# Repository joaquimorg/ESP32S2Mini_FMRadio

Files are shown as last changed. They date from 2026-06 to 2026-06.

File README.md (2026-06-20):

🌐 **Português** · [English](README.en.md)

# ESP32-S2 Mini — Rádio FM (SI4703)

Firmware de um rádio FM para **Lolin S2 Mini (ESP32-S2)** com um pequeno LCD
**ST7789 de 76×284 px** usado em orientação paisagem (**284×76**).

O projeto inclui uma interface gráfica completa (7 ecrãs) com navegação por
4 botões físicos e controlo de um **SI4703** (FM + RDS) por I²C. As memórias e a
última sintonia/volume são **guardadas em NVS** (sobrevivem a desligar).

> Existe um interruptor `#define USE_SI4703` no topo de [src/main.cpp](src/main.cpp):
> a `1` usa o rádio real, a `0` usa um modelo simulado em RAM (útil para testar a UI).

---

## Hardware

- **MCU:** Lolin S2 Mini (ESP32-S2FNR2, 4 MB Flash, 2 MB PSRAM)
- **Display:** TFT ST7789, painel de **76×284 px** (offset dentro da RAM 240×320 do controlador)
- **Rádio:** SI4703 (FM + RDS), via I²C
- **Entrada:** 4 botões físicos (por baixo do display)
- **Áudio:** amplificador PAM8403 (2×3 W) + altifalante 8 Ω / 3 W

### Componentes

| Componente | Imagem | Descrição |
|---|:---:|---|
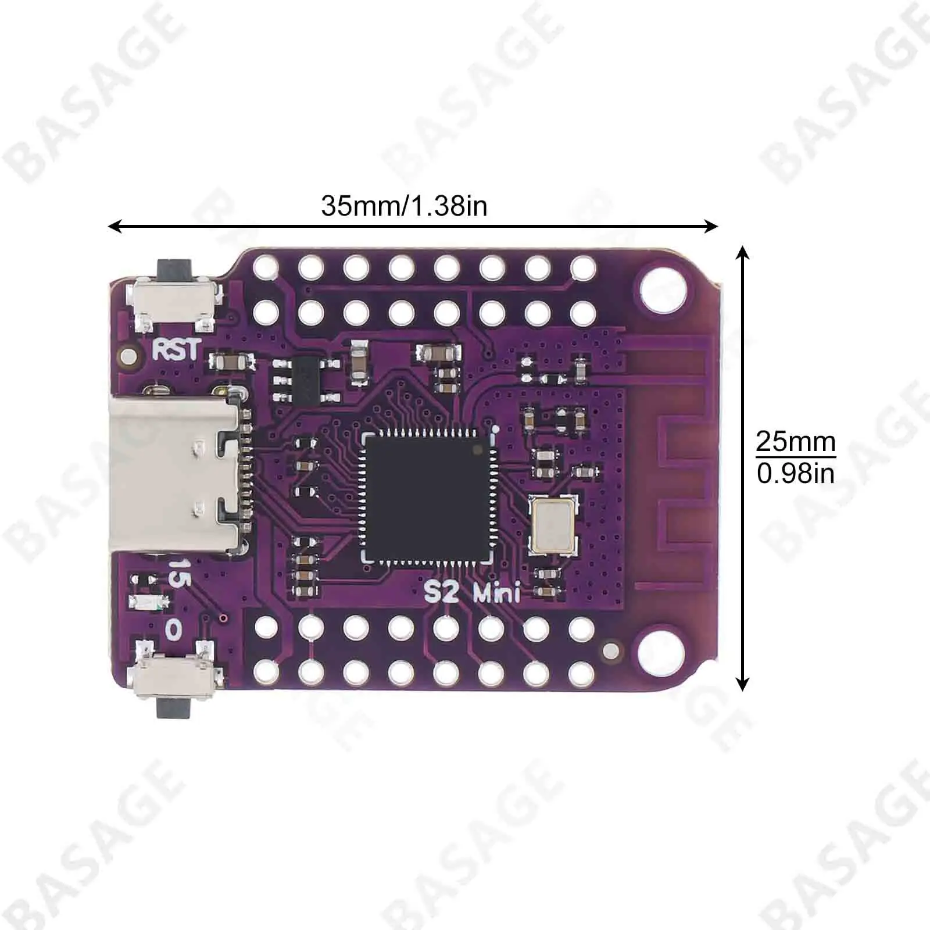
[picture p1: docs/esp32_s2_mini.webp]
| **Lolin S2 Mini** |  | MCU ESP32-S2 (35×25 mm), 4 MB Flash + 2 MB PSRAM, USB-C nativo. |
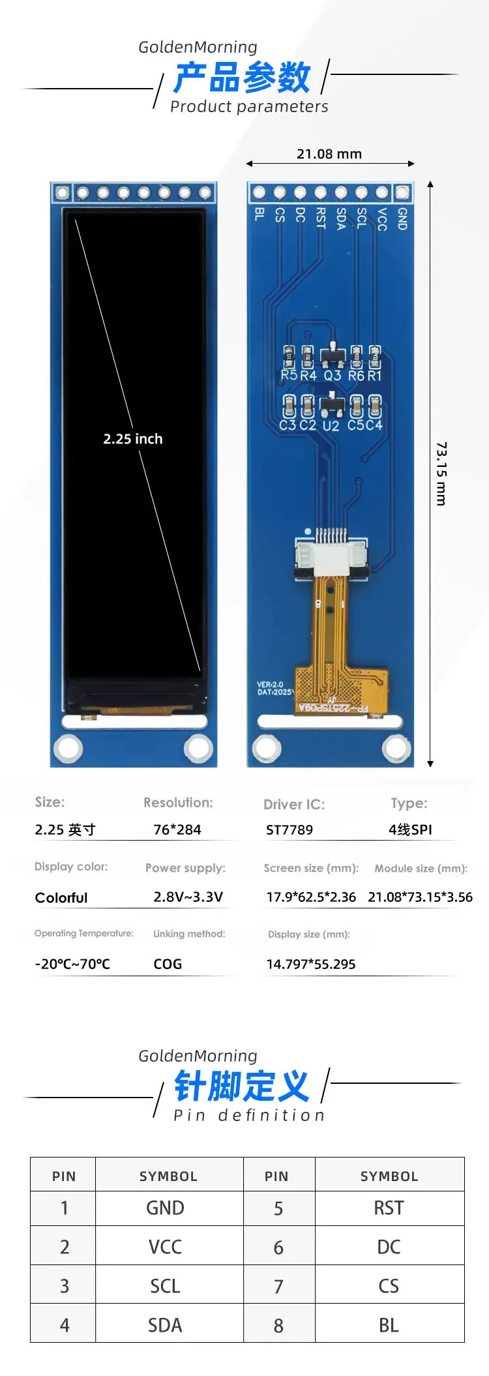
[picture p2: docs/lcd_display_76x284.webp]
| **Display ST7789** |  | TFT 2.25" a cores, 76×284 px, interface SPI de 4 fios, alimentação 2.8–3.3 V. |
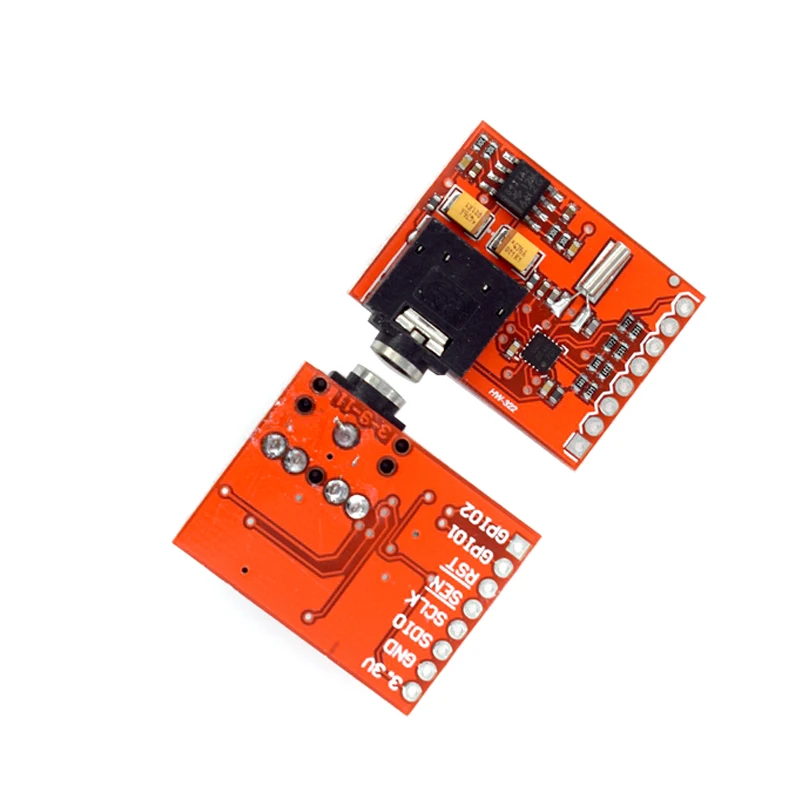
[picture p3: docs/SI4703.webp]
| **SI4703** |  | Recetor FM com RDS por I²C; jack de 3.5 mm que serve também de antena. |
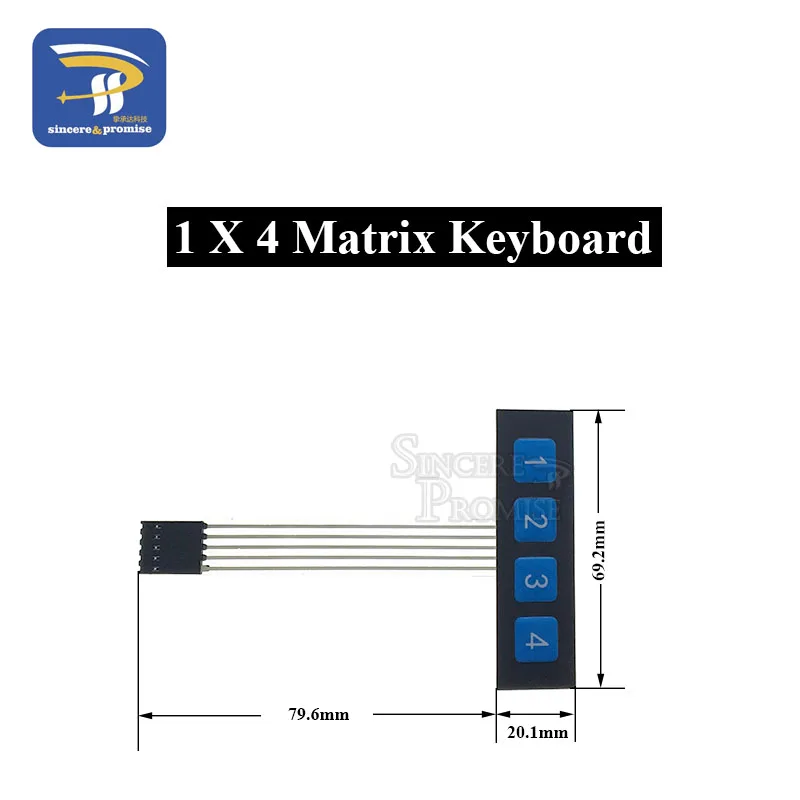
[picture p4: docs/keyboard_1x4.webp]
| **Teclado 1×4** |  | Membrana com 4 botões (BT1–BT4) usada para a navegação. |
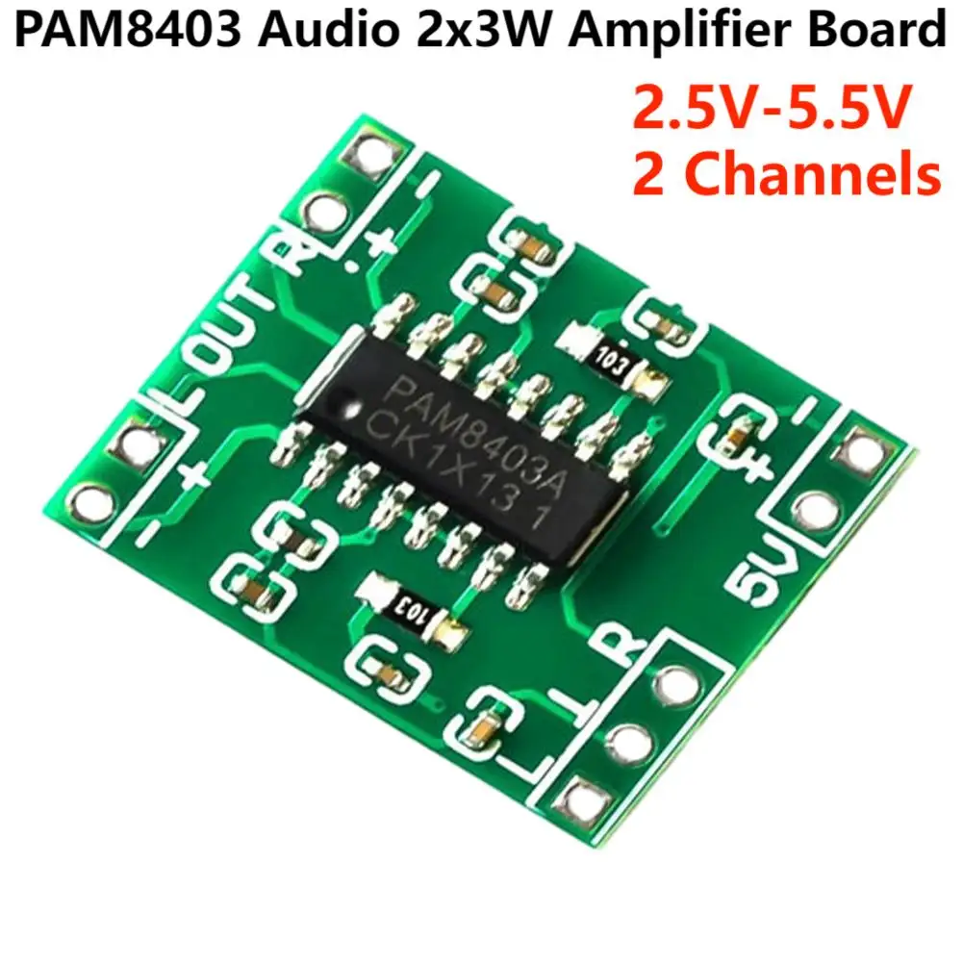
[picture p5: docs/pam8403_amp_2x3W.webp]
| **Amplificador PAM8403** |  | Amplificador classe-D estéreo 2×3 W, alimentação 2.5–5.5 V. |
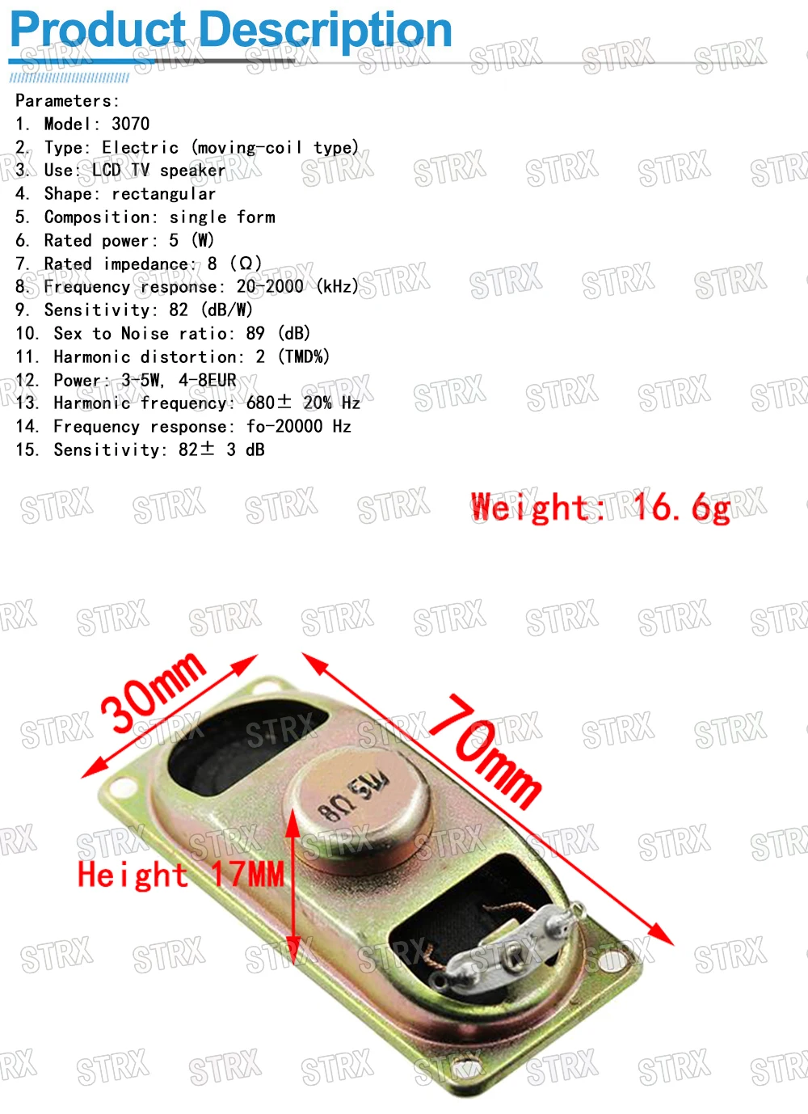
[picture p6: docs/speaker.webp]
| **Altifalante** |  | Altifalante retangular 8 Ω / 3 W (70×30 mm) para a saída de áudio. |

---

## Pinout

### Display ST7789 (SPI)

| Sinal | GPIO |
|---|---|
| MOSI  | 35 |
| SCLK  | 36 |
| MISO  | 40 |
| CS | 34 |
| DC | 37 |
| RST | 38 |

> O painel é de 76×284 mas o controlador tem RAM de 240×320. A imagem é desenhada
> num *sprite* lógico de **284×76** e copiada para a janela do painel com **offset
> `OX=82, OY=18`** e rotação de 90° (ver `show()` em [src/main.cpp](src/main.cpp)).
> As cores estão invertidas no painel, por isso é usado `tft.invertDisplay(false)`.

### Teclado de membrana 1×4

Tira única com **5 pinos**: uma linha **comum (COM)** mais as 4 teclas. Cada tecla
liga a sua linha ao COM. O **COM liga diretamente a `GND`** e cada tecla é lida com
`INPUT_PULLUP` (premir → pino a LOW).

> ⚠️ O COM tem de ir a **GND** — **nunca** a `3V3`/`5V` nem a um GPIO conduzido. Uma
> ligação errada do COM a uma linha de alimentação cria um **curto** (regulador a
> aquecer / boot loop).

| Sinal | GPIO |
|---|---|
| COM | GND  |
| Tecla 1 | 1 |
| Tecla 2 | 2 |
| Tecla 3 | 3 |
| Tecla 4 | 4 |

### SI4703 — FM/RDS (I²C)

| Sinal | GPIO |
|---|---|
| SDA / SDIO | 8 |
| SCL / SCLK | 9 |
| RST | 7 |

> O SI4703 requer uma sequência de reset específica (SDIO a LOW durante o flanco
> de subida do RST, para selecionar o modo I²C de 2 fios). Isto é feito
> **manualmente** no `setup()` *antes* do `Wire.begin()`, para a biblioteca não
> repetir o reset e voltar a ocupar o pino SDA. Usa-se a
> [`mathertel/Radio`](https://github.com/mathertel/Radio) (SI4703 + RDS).
> O módulo precisa de **pull-ups** (~4.7 kΩ) em SDA/SCL — a maioria das placas já os traz.

### Diagrama de ligações

**Sinais (dados) — para o ESP32:**

```
                          ┌───────────────────────────┐
                          │      Lolin S2 Mini         │
                          │        (ESP32-S2)          │
                          │                            │
   ┌──────────────┐       │                            │       ┌──────────────┐
   │  TFT ST7789  │       │                            │       │   SI4703 FM  │
   │   76 x 284   │       │                            │       │   (I2C/RDS)  │
   │              │       │                            │       │              │
   │  MOSI/SDA ───┼───────┤ 35                       8 ├───────┼─ SDIO (SDA)  │
   │  SCLK     ───┼───────┤ 36                       9 ├───────┼─ SCLK (SCL)  │
   │  MISO     ───┼───────┤ 40                       7 ├───────┼─ RST         │
   │  CS       ───┼───────┤ 34                         │       │  L/R OUT ─┐  │
   │  DC       ───┼───────┤ 37                         │       │  ANT ── fio  │
   │  RST      ───┼───────┤ 38                         │       └───────────┼──┘
   │  VCC ◄ 3V3* │        │   1    2    3    4   GND    │                   │ áudio
   │  BLK ◄ 3V3* │        │   │    │    │    │    │     │                   ▼
   │  GND ── GND  │       └───┼────┼────┼────┼────┼────┘        ┌─────────────────┐
   └──────────────┘          │    │    │    │    │ COM ── GND   │ PAM8403  2x3W   │
                           ┌──┴────┴────┴────┴────┴┐            │  IN  ◄ L/R OUT  │
                           │  [1] [2] [3] [4]  COM │  teclado   │  OUT ─► colunas │
                           └───────────────────────┘  1x4       │  VCC ◄ 3V3*     │
                                                                 └─────────────────┘
   * VCC/BLK dos periféricos NÃO vêm do pino 3V3 do Lolin — vêm do BUCK (ver abaixo).
   Teclado: cada tecla liga a sua linha (GPIO1-4) ao COM; COM a GND (NUNCA a 3V3/5V).
```

**Alimentação — tudo a 3.3 V a partir do buck externo:**

```
   Powerbank 5V ──┬───────────────► 5V  do Lolin S2 Mini  (→ reg. interno → MCU)
                  │
                  └─► Buck 3.3V ───► 3V3* ──┬─► Display  VCC + BLK
                      (≥2A, ex.            ├─► SI4703   VCC
                       MP1584)             └─► PAM8403  VCC   (+ cap. 470–1000µF)
   GND ── comum a TUDO (powerbank, buck, ESP32, display, SI4703, amp, colunas)
```

> **Nota:** o LCD usa `MOSI` (linha de dados SPI) e o SI4703 usa `SDIO` (dados I²C) —
> são barramentos **independentes**, apesar de na placa rádio o pino se chamar "SDA".

### Alimentação

A alimentação é reaproveitada de uma **pequena powerbank** (célula LiPo 1S +
placa com carregador tipo TP4056 e *boost* para 5 V). A saída **5 V** USB
alimenta o sistema e o **GND** é comum a tudo.

O regulador interno do Lolin S2 Mini é fraco (~300–500 mA) e **não aguenta o
amplificador** — foi o que o pôs a aquecer. Por isso usa-se um **regulador de
3.3 V externo** (idealmente um *buck*, ex. **MP1584** de ≥ 2 A — aquece pouco;
um AMS1117 também serve mas dissipa mais) que alimenta **todos os periféricos a
3.3 V: display, SI4703 e amplificador PAM8403**. O ESP32 continua a ser
alimentado pelos **5 V** (pino `5V`, regulador interno só para o MCU).

```
   Powerbank 5V ──┬── Lolin S2 Mini (pino 5V → reg. interno → 3V3 só do MCU)
                  │
                  └── Regulador 3.3V externo (buck, ≥2A) ──┬── Display VCC (3V3)
                                                           ├── SI4703 VCC (3V3)
                                                           └── PAM8403 VCC (3V3)
   GND comum a TODOS os blocos
```

> - **Ajusta o buck para 3.3 V** (mede com o multímetro) **antes** de ligar os
>   periféricos.
> - **Não unir** a saída do buck ao pino `3V3` do Lolin (não juntar dois
>   reguladores). O ESP32 fica no seu próprio 3V3 (via `5V`); os periféricos no buck.
> - Como ambos os lados são 3.3 V, o I²C/SPI continua compatível (sem level shifting).
> - **GND comum** obrigatório entre powerbank, buck, ESP32 e todos os periféricos.
> - Põe um **condensador de reservatório** (~470–1000 µF) junto ao amplificador
>   (+ 100 nF de desacoplamento) para os picos de corrente do áudio.
> - A 3.3 V o PAM8403 dá **menos potência** (~0.5 W/canal) do que a 5 V — é o
>   compromisso de manter tudo no mesmo rail.

### Leitura da carga (LiPo)

Para mostrar a carga no ecrã, lê-se a tensão da **célula** (`B+`, 3.0–4.2 V) com o
ADC. Como o ADC do ESP32-S2 só aceita até ~3.3 V, usa-se um **divisor resistivo
1:2** (R1 = R2 = 100 kΩ): 4.2 V → 2.1 V (dentro da escala). O firmware lê em
**GPIO6** (ADC1) e multiplica por 2.

```
        B+ (célula) ──[ R1 100kΩ ]──┬──[ R2 100kΩ ]── GND
                                    │
                                    ├───────────────── GPIO6 (ADC1)   Vadc = Vbat / 2
                                    │
                                  ──┴── C1 100nF (opcional, filtra ruído)
                                    │
                                   GND
```

> - Ligar o `B+` exige abrir a powerbank — **respeitar a polaridade**; GND comum.
> - Com R1 = R2 = 100 kΩ o consumo do divisor é ~21 µA (desprezável).
> - Muitas powerbanks pequenas **desligam o boost** com consumos baixos (< ~50 mA).
> - A percentagem é uma estimativa por troços da curva de descarga 1S; podes
>   desligar tudo com `#define USE_BATTERY 0` em [src/main.cpp](src/main.cpp).

---

## Caixa 3D (impressão)

Caixa modelada em **OpenSCAD**, em duas peças (corpo + frente), pensada para
**imprimir sem suportes**. A frente tem o recorte do LCD, duas grelhas de
altifalante em ranhuras verticais, a fenda para a fita do teclado de membrana e a
etiqueta "FM RADIO" gravada. O fecho é por **4 postes** com parafusos **M3** pela
traseira.

| Vista frontal | Vista isométrica |
|:---:|:---:|
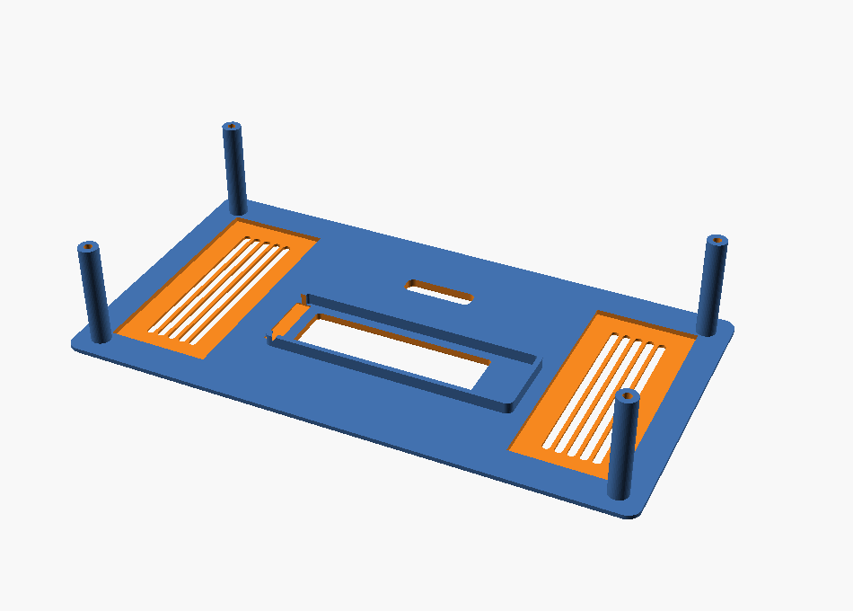
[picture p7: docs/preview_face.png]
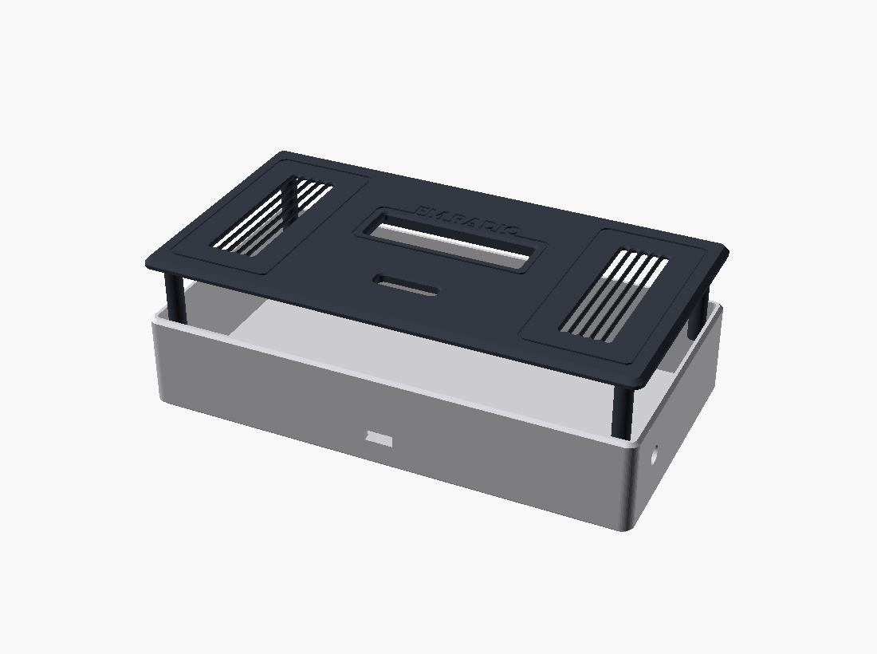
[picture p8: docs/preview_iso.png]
|  |  |

- **Dimensões exteriores:** ≈ **163 × 93 × 37 mm** (L × A × P).
- **Paredes / base / frente:** 2.4 / 2.4 / 3.0 mm; cantos arredondados e bordos
  chanfrados a 45°.
- **Aberturas laterais:** USB-C e jack de antena.

### Ficheiros ([docs/](docs/))

| Ficheiro | Conteúdo |
|---|---|
| [docs/fmradio_case.scad](docs/fmradio_case.scad) | Fonte paramétrica (OpenSCAD). |
| [docs/body.stl](docs/body.stl) | Corpo, pronto a fatiar. |
| [docs/faceplate.stl](docs/faceplate.stl) | Frente, pronta a fatiar. |

### Orientação de impressão

- **faceplate:** face exterior (lisa) **para baixo**; os postes apontam para cima.
- **body:** abertura **para cima**.

### Regerar os STL a partir do `.scad`

```bash
openscad -D 'part="body"'      -o docs/body.stl      docs/fmradio_case.scad
openscad -D 'part="faceplate"' -o docs/faceplate.stl docs/fmradio_case.scad
```

> Os parâmetros (paredes, recortes do LCD/altifalantes, postes, etc.) estão no topo
> de [docs/fmradio_case.scad](docs/fmradio_case.scad) e podem ser ajustados.

---

## Ecrãs

1. **Splash** — banner animado de arranque (antena com ondas de rádio + equalizador).
2. **Principal** — estação/frequência a tocar:
   - **Sem RDS:** a frequência centrada e o volume (`VOL x`) no topo direito.
   - **Com RDS:** nome da estação em grande, frequência pequena no topo direito e
     *radiotext* com scroll horizontal. O volume aparece no topo ao centro e,
     quando a frequência é uma memória, mostra `P0X` antes da frequência.
3. **Sintonia (Tune)** — ajuste manual da frequência, com passo configurável
   (0.10 / 0.05, alternado com o **clique longo no botão 2**). Mostra o nome da
   estação RDS no topo (quando disponível).
4. **Volume** — nível 0–30, com *mute*.
5. **Presets** — memórias guardadas (até 20, em páginas de 4). Vazio por defeito.
   Ao abrir, fica já selecionada a memória da frequência atual (se houver).
6. **Scan** — procura automática com **auto-store** (ver abaixo).
7. **Menu** — Rádio / Presets / Volume / Scan / Sobre.
8. **Mensagem** — confirmações (ex.: "Estação guardada"), auto-fecho em 2,5 s.

A barra inferior de cada ecrã mostra as funções dos 4 botões; **os botões 3D são
físicos** (por baixo do display) e não fazem parte do desenho.

---

## Rádio e memórias

- **RDS:** o nome da estação (PS) e o *radiotext* são lidos do SI4703. O
  `checkRDS()` corre a cada iteração do loop para não perder grupos. Sem RDS, o
  ecrã principal mostra apenas a frequência centrada.
- **Memórias:** até **20**, vazias por defeito. Guardadas em **NVS** (`Preferences`,
  namespace `fmradio`) — sobrevivem a desligar.
- **Scan (auto-store):** acede-se pelo **Menu → Scan**. O ecrã abre **em espera**;
  a procura só arranca ao premir o **botão 1**. Ao iniciar **apaga todas as
  memórias**, começa no **início da banda** (87.5 MHz) e percorre-a com `seekUp`.
  Em cada estação, só guarda se houver **estéreo + nome RDS estável** (o nome tem
  de se manter igual ~1,5 s; espera até 7 s por estação). Termina ao dar a volta à
  banda ou ao atingir 20 memórias.
- **Restauro ao ligar:** a última **frequência, volume e mute** são gravados em
  NVS (com escrita atrasada de 2 s para poupar a flash) e repostos no arranque.

---

## Navegação

**Atalhos globais (clique longo ≈ 700 ms):**

| Botão (longo) | Ação |
|---|---|
| 1 | → Sintonia |
| 4 | → Menu |

**Cliques curtos por ecrã:**

| Ecrã | 1 | 2 | 3 | 4 |
|---|---|---|---|---|
| Principal | freq − | freq + | → Volume | → Presets |
| Volume | vol − | vol + | Mute | OK → Principal |
| Sintonia  | freq − | freq + | Guardar memória | Sair |
| Presets | anterior | seguinte | OK (sintoniza)¹ | Sair |
| Scan | Iniciar / Stop | — | — | Sair |
| Menu | ◄ | ► | OK (entra) | Sair |
| Mensagem  | fecha | — | — | — |

> No **Sintonia**, o passo (0.10 / 0.05) muda-se com o **clique longo no botão 2**.
>
> ¹ Nos **Presets**, o **clique longo no botão 3** apaga a memória selecionada.

**Timeout de inatividade:** em qualquer ecrã que não o Principal, ao fim de
**30 s** sem interação volta ao Principal (exceto durante o Scan).

---

## Teste via Serial

Para testar a navegação sem premir os botões físicos, usa o **Serial Monitor**
(115200 baud):

| Tecla | Equivalente |
|---|---|
| `1` `2` `3` `4` | clique curto dos botões 1–4 |
| `q` `w` `e` `r` | clique longo dos botões 1–4 |

---

## Build & Upload (PlatformIO)

```bash
pio run            # compilar
pio run -t upload  # gravar (porta COM definida no platformio.ini)
pio device monitor # consola serie
```

Configuração relevante em [platformio.ini](platformio.ini):

- `board = lolin_s2_mini`, `framework = arduino`
- `ARDUINO_USB_CDC_ON_BOOT=1` (Serial por USB CDC nativo)
- TFT_eSPI configurada por `build_flags` (driver ST7789, pinos, fontes, RGB BGR)
- Fontes carregadas: GLCD, 2, 4, 6, 7, GFXFF (FreeSans usada no *radiotext*)

---

## Estrutura

```
ESP32S2Mini_FMRadio/
├── platformio.ini      # configuração da board + TFT_eSPI (build_flags)
├── src/
│   └── main.cpp        # UI, máquina de estados, SI4703 e persistência (NVS)
├── docs/               # imagens do hardware + caixa 3D (.scad / .stl)
├── README.md           # Português
└── README.en.md        # Inglês
```

---

## Próximos passos

- [x] Ligar o SI4703 e ativar as chamadas reais.
- [x] Ler RDS real (nome da estação + radiotext) do SI4703.
- [x] Persistir memórias e última sintonia/volume na NVS (flash).
- [x] Remoção individual de memórias (clique longo no botão 3 nos Presets).
- [x] Indicador de nível de bateria da LiPo (ADC + divisor 1:2 — ver esquema acima).
- [ ] Validar os 4 botões físicos no hardware final
      (o firmware já regista cada clique no Serial para ajudar nesta verificação).

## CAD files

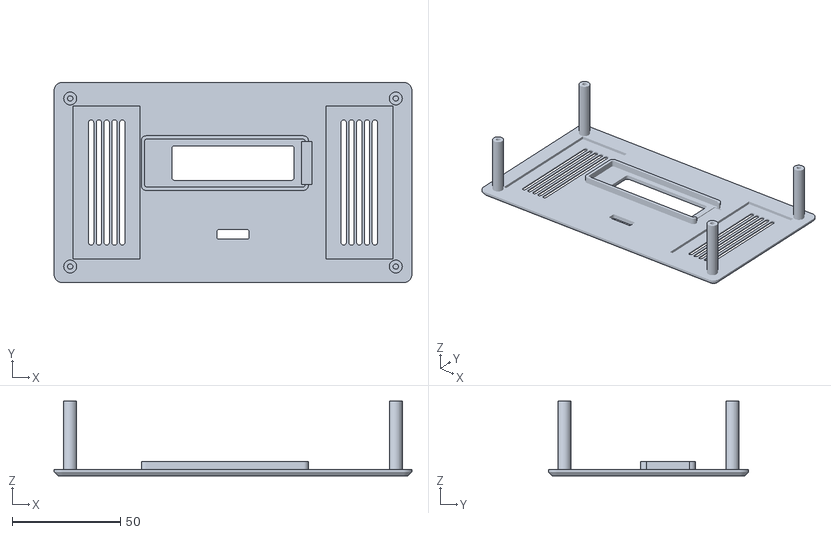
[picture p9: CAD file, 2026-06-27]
docs/faceplate.stl
165.7 x 92.8 x 34.5

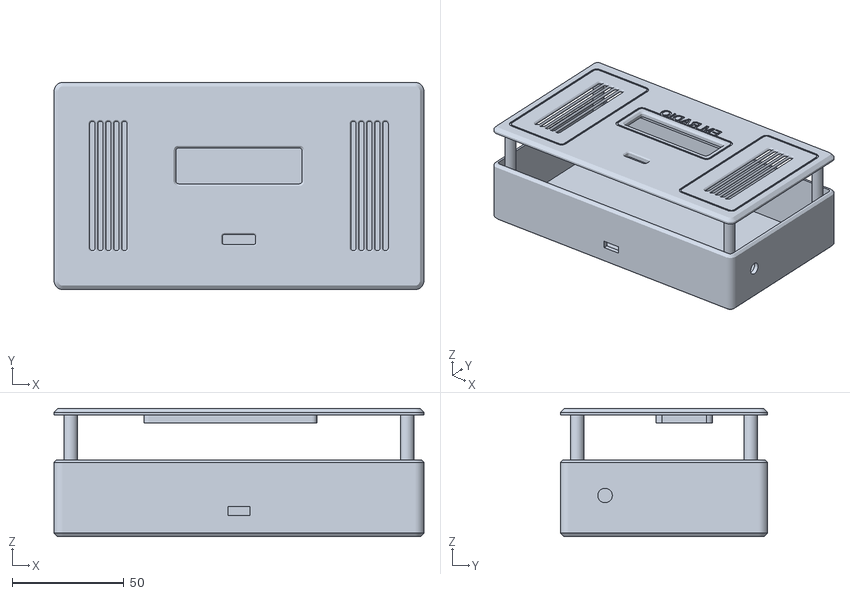
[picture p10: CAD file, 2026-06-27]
docs/FMRadio_plate.stl
165.7 x 92.8 x 57.4

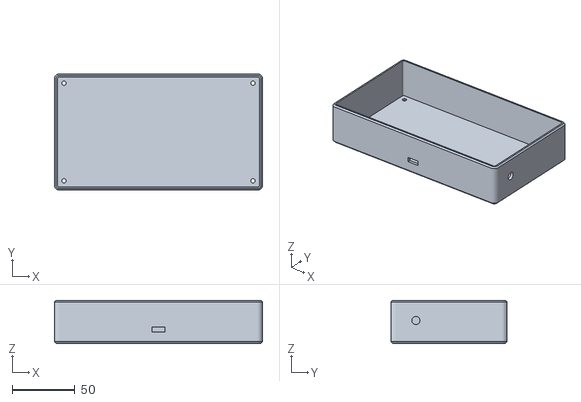
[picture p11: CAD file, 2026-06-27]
docs/body.stl
165.7 x 92.8 x 34.4

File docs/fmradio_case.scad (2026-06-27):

// =====================================================================
//  Caixa 3D para Radio FM ESP32-S2 Mini (SI4703)  -- v2 "PRO"
//  Projeto: github.com/joaquimorg/ESP32S2Mini_FMRadio
//
//  Acabamento mais cuidado, IMPRESSAO SEM SUPORTES:
//   - bordos chanfrados (bisel a 45 graus)
//   - ecra com moldura/bisel encastrado
//   - grelhas em ranhuras verticais (visual moderno)
//   - molduras gravadas a volta do LCD e dos altifalantes
//   - etiqueta gravada ("FM RADIO")
//
//  Orientacao de impressao:
//   - faceplate : face EXTERIOR para baixo (lisa); postes apontam p/ cima
//   - body      : abertura para cima
//
//  Render por peca:
//   openscad -D 'part="body"'      -o body.stl      fmradio_case.scad
//   openscad -D 'part="faceplate"' -o faceplate.stl fmradio_case.scad
// =====================================================================

part = "preview";     // "body" | "faceplate" | "preview"
$fn = 48;
eps = 0.02;

// ---------------------------------------------------------------------
//  PARAMETROS GERAIS  (mm)
// ---------------------------------------------------------------------
wall       = 2.4;
floor_t    = 2.4;
face_t     = 3.0;
corner_r   = 4.0;
interior_d = 32;

edge_margin = 7;
tb_margin   = 9;
gap_spk_lcd = 1;

// chanfros (bisel) -- todos a 45 graus => imprimem sem suporte
face_chamf  = 1.8;
body_base_chamf = 1.6;
body_top_chamf  = 1.2;
open_chamf  = 1.0;

// gravacoes
engrave_d   = 0.6;
engrave_w   = 1.0;

// ---------------------------------------------------------------------
//  ALTIFALANTES (2x 70 x 30, na vertical) -- grelha em ranhuras
// ---------------------------------------------------------------------
spk_long  = 70;
spk_short = 30;
spk_recess_depth = 1.6;
grille_margin   = 6;
grille_slots    = 5;
grille_slot_w   = 2.4;
grille_frame_gap = 3.5;

// ---------------------------------------------------------------------
//  LCD ST7789 76x284  --  medidas REAIS da folha (GoldenMorning 8 pinos)
//
//  Em PAISAGEM (comprimento na horizontal):
//    PCB 73.15 x 21.08 | LCM 62.5 x 17.9 | LCD 60.55 x 17 |
//    POL 57.25 x 16.7 | Area activa 55.295 x 14.797
//  A area activa esta centrada no vidro; o PCB tem ~3.78 mm de desvio
//  (fila de 8 pinos num topo, 2 furos Ø2.5 no outro).
//  >> ORIENTACAO ASSUMIDA: pinos do lado DIREITO (+X) <<
//     (se montares com os pinos a esquerda: lcd_aa_off_x = -3.78 e lcd_fpc_side = 2)
// ---------------------------------------------------------------------
lcd_mod_w     = 73.15;  // contorno PCB (dim. MAIOR, paisagem)
lcd_mod_h     = 21.08;  // contorno PCB (dim. MENOR)
lcd_mod_clear = 0.5;    // folga do encaixe, por lado
lcd_frame_h   = 3.5;    // altura das paredes de retencao (para dentro)
lcd_frame_wall= 1.6;    // espessura das paredes de retencao

lcd_aa_w = 55.295;      // area ACTIVA visivel (dim. maior)
lcd_aa_h = 14.797;      // area ACTIVA visivel (dim. menor)
lcd_aa_off_x = 3.78;    // desvio da area activa vs centro do PCB (pinos a +X)
lcd_aa_off_y = 0;       // (centrada no eixo curto)
lcd_win_margin = 0.6;   // janela = area activa + esta folga

lcd_fpc_w    = 20;      // folga p/ a fila de 8 pinos / fios (no topo dos pinos)
lcd_fpc_side = 3;       // lado dos pinos: 0=baixo 1=cima 2=esq 3=dir

lcd_offset_y = 9;       // posicao vertical do ecra na frente
lcd_frame_gap = 3.5;    // moldura gravada a volta da janela

// largura central reservada (mantem o ECRA centrado, contendo o PCB desviado)
center_w = lcd_mod_w + 2*lcd_mod_clear + 2*lcd_frame_wall + 2*abs(lcd_aa_off_x);

// ---------------------------------------------------------------------
//  MEMBRANA 1x4 (cola por fora) -- passagem da fita E DA FICHA
//  A abertura tem de deixar passar o conetor (mede a tua ficha!).
// ---------------------------------------------------------------------
slot_gap_from_lcd = 25;
cable_slot_w = 15;     // largura da abertura (>= largura da ficha)
cable_slot_h = 4.5;    // altura da abertura (>= espessura da ficha)
cable_slot_r = 1.0;

// ---------------------------------------------------------------------
//  ETIQUETA gravada
// ---------------------------------------------------------------------
label_text = "FM RADIO";
label_font = "Poppins:style=Bold";
label_size = 6.0;
label_y_above_lcd = 6.5;

// ---------------------------------------------------------------------
//  FIXACAO (4 postes nos cantos, parafuso M3 pela traseira)
// ---------------------------------------------------------------------
post_r        = 3.0;
post_inset    = 7.5;
post_pilot_d  = 2.5;
screw_clear_d = 3.4;
screw_head_d  = 6.5;
screw_head_h  = 2.2;

// ---------------------------------------------------------------------
//  ABERTURAS laterais
// ---------------------------------------------------------------------
usb_w = 10; usb_h = 4.0; usb_z = 9;
ant_jack = true; ant_d = 6.5; ant_y = 20;

// ---------------------------------------------------------------------
//  DIMENSOES EXTERIORES (calculadas)
// ---------------------------------------------------------------------
interior_w = edge_margin + spk_short + gap_spk_lcd + center_w
             + gap_spk_lcd + spk_short + edge_margin;
interior_h = tb_margin + spk_long + tb_margin;
W = interior_w + 2*wall;
H = interior_h + 2*wall;
D = floor_t + interior_d + face_t;

spk_l_x = wall + edge_margin + spk_short/2;
spk_r_x = W - spk_l_x;
spk_cy  = H/2;
cen_x   = W/2;
lcd_cy  = H/2 + lcd_offset_y;
lcd_win_h_eff = lcd_aa_h + 2*lcd_win_margin;   // altura efectiva da janela (area activa)
lcd_win_w_eff = lcd_aa_w + 2*lcd_win_margin;   // largura efectiva da janela
mem_cy  = lcd_cy - lcd_win_h_eff/2 - slot_gap_from_lcd;

echo(str(">>> EXTERIOR: ", W, " x ", H, " x ", D, " mm"));

// =====================================================================
//  HELPERS
// =====================================================================
module rrect(w, h, r) { offset(r=r) offset(delta=-r) square([w,h], center=true); }

module cham_prism(w, h, d, r, cb, ct) {
    if (cb > 0)
        hull() {
            linear_extrude(eps) rrect(w-2*cb, h-2*cb, max(r-cb,0.5));
            translate([0,0,cb]) linear_extrude(eps) rrect(w, h, r);
        }
    translate([0,0,cb]) linear_extrude(d - cb - ct) rrect(w, h, r);
    if (ct > 0)
        hull() {
            translate([0,0,d-ct]) linear_extrude(eps) rrect(w, h, r);
            translate([0,0,d-eps]) linear_extrude(eps) rrect(w-2*ct, h-2*ct, max(r-ct,0.5));
        }
}

module rect_cut_chamf(cx, cy, w, h, rr, ch, thru) {
    translate([cx, cy, 0]) {
        hull() {
            translate([0,0,-eps]) linear_extrude(eps) rrect(w+2*ch, h+2*ch, rr+ch);
            translate([0,0,ch])   linear_extrude(eps) rrect(w, h, rr);
        }
        translate([0,0,ch-eps]) linear_extrude(thru) rrect(w, h, rr);
    }
}

module engrave_frame(cx, cy, w, h, r) {
    translate([cx, cy, -eps]) linear_extrude(engrave_d+eps)
        difference() {
            rrect(w+engrave_w, h+engrave_w, r);
            rrect(w-engrave_w, h-engrave_w, max(r-engrave_w,0.4));
        }
}

// ranhura vertical em capsula (hull de 2 circulos) com boca chanfrada
module vslot_cut(cx, cy, w, len, ch, thru) {
    module cap(extra) {
        hull() {
            translate([0,  (len-w)/2, 0]) circle(d = w + 2*extra, $fn = 28);
            translate([0, -(len-w)/2, 0]) circle(d = w + 2*extra, $fn = 28);
        }
    }
    translate([cx, cy, 0]) {
        hull() {
            translate([0,0,-eps]) linear_extrude(eps) cap(ch);
            translate([0,0,ch])   linear_extrude(eps) cap(0);
        }
        translate([0,0,ch-eps]) linear_extrude(thru) cap(0);
    }
}

module grille_slots_cut(cx, cy) {
    aw = spk_short - 2*grille_margin;
    sl = spk_long  - 2*grille_margin;
    n  = grille_slots;
    px = aw / n;
    for (i = [0:n-1])
        vslot_cut(cx - aw/2 + px/2 + i*px, cy, grille_slot_w, sl, open_chamf*0.6, face_t);
}

module speaker_pocket(cx, cy) {
    translate([cx, cy, face_t - spk_recess_depth])
        linear_extrude(spk_recess_depth + 1)
            square([spk_short + 1, spk_long + 1], center=true);
}

// -- LCD: paredes de retencao com o contorno do modulo (registo) --
//    centro do encaixe = centro da janela menos o offset da area activa
function lcd_pkt_cx() = cen_x   - lcd_aa_off_x;
function lcd_pkt_cy() = lcd_cy  - lcd_aa_off_y;

module lcd_frame_add() {
    fo_w = lcd_mod_w + 2*lcd_mod_clear + 2*lcd_frame_wall;
    fo_h = lcd_mod_h + 2*lcd_mod_clear + 2*lcd_frame_wall;
    fi_w = lcd_mod_w + 2*lcd_mod_clear;
    fi_h = lcd_mod_h + 2*lcd_mod_clear;
    translate([lcd_pkt_cx(), lcd_pkt_cy(), face_t])
        linear_extrude(lcd_frame_h)
            difference() {
                rrect(fo_w, fo_h, lcd_frame_wall + 0.6);
                rrect(fi_w, fi_h, 0.8);
            }
}
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

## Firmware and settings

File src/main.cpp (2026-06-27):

// ============================================================
//  ESP32-S2 Mini + ST7789 76x284 (paisagem 284x76)
//  Radio FM SI4703 - FIRMWARE (UI + navegacao)
// ------------------------------------------------------------
//  Hardware (sugestao de pinos):
//    Display ST7789 : MOSI35 SCLK36 MISO40 CS34 DC37 RST38
//    Teclado 1x4    : COM=GND ; teclas 1..4 = GPIO1 GPIO2 GPIO3 GPIO4 (pullup)
//    SI4703 (I2C)   : SDA=GPIO8 SCL=GPIO9 RST=GPIO7
//    Bateria LiPo   : GPIO6 (ADC1) via divisor 1:2 da celula (ver README)
//
//  A radio esta SIMULADA (modelo em RAM). Os pontos de
//  integracao com o SI4703 estao marcados com TODO[SI4703].
//
//  Teste sem hardware: comandos pelo Serial ->
//    '1'..'4' = clique curto ;  'q' 'w' 'e' 'r' = clique longo
// ============================================================

#include <Arduino.h>
#include <TFT_eSPI.h>
#include <Wire.h>
#include <Preferences.h>
#include <radio.h>
#include <SI4703.h>
#include "RDSParserLocal.h"   // copia local (descodificacao de RadioText melhorada)

// fontes smooth (anti-aliased VLW, embebidas em FLASH) - contornos suavizados
#include "NotoSansBold15.h"
#include "Latin_Hiragana_24.h"
#define FF_BIG   (Latin_Hiragana_24)   // frequencia / nome estacao / volume (24px)
#define FF_TITLE (NotoSansBold15)      // titulos dos ecras (15px, bold)

// 1 = usa o SI4703 real ; 0 = modelo simulado em RAM
#define USE_SI4703 1

// 1 = le a carga da LiPo (divisor resistivo no ADC) ; 0 = desliga o indicador
#define USE_BATTERY 1

// pinos do SI4703 (I2C + reset)
static const uint8_t PIN_SDA = 8, PIN_SCL = 9, PIN_RST = 7;

// medicao da bateria: GPIO6 = ADC1, le o ponto medio de um divisor 1:2 (R1=R2)
// ligado a celula LiPo (B+). Vbat = 2 x Vadc. Ver esquema no README.
static const uint8_t PIN_VBAT = 6;
static const float   VBAT_DIV = 2.0f;     // razao do divisor (R1=R2=100k)

SI4703 radio;
RDSParserLocal rds;

TFT_eSPI tft = TFT_eSPI();

// --- Painel fisico dentro da RAM 240x320 do controlador ---
static const int16_t PW = 76;
static const int16_t PH = 284;
static const int16_t OX = 82;
static const int16_t OY = 18;

// --- Tela logica (paisagem) ---
static const int16_t LW = 284;
static const int16_t LH = 76;

TFT_eSprite cv = TFT_eSprite(&tft);

// --- Teclado de membrana 1x4 ---
// Tira unica com 5 pinos: 1 linha comum (COM) + 4 teclas. Cada tecla liga a
// sua linha ao COM. O COM liga DIRETAMENTE a GND (NAO a um GPIO nem a 3V3/5V) e
// cada tecla e' lida com pull-up interno (premir -> pino a LOW).
// (Antes o COM era conduzido pelo GPIO5; passou a GND para evitar que um pino
//  ficasse em curto com a alimentacao em caso de erro de ligacao.)
static const uint8_t BTN_PIN[4] = {2, 1, 4, 3}; // teclas 1..4

// --- Paleta (RGB565) ---
#define COL_BG      TFT_BLACK
#define COL_CYAN    0x07FF
#define COL_BLUE    0x051F
#define COL_GREEN   0x07E0
#define COL_ORANGE  0xFD20
#define COL_WHITE   0xFFFF
#define COL_GREY    0x8410
#define COL_DKGREY  0x39E7
#define COL_FRAME   0x10A2

// =================== ESTADO DA RADIO =======================
enum Screen { SC_MAIN, SC_TUNE, SC_VOLUME, SC_PRESETS, SC_SCAN, SC_MENU, SC_MSG };

struct Preset { float f; char name[12]; };
const int MAX_PRESET = 20;
Preset presets[MAX_PRESET];
int nPresets = 0;             // sem memorias por defeito

// limites da banda FM (MHz)
const float FM_MIN = 87.5f, FM_MAX = 108.0f;

struct State {
  Screen screen = SC_MAIN;
  float  freq   = FM_MIN;
  float  step   = 0.10f;
  int    volume = 14;
  bool   muted  = false;
  bool   stereo = false;
  int    rssi   = 0;          // 0..5
  bool   hasRDS = false;
  String station = "";
  String radiotext = "";
  int    presetSel = 0;
  int    menuSel   = 0;
  bool   scanning  = false;
  // bateria (LiPo)
  bool   battValid = false;   // ja foi feita uma leitura valida
  int    battPct   = 0;       // 0..100 (estimativa)
  float  battV     = 0.0f;    // tensao da celula (V)
  // mensagem
  String msgTitle, msgL1, msgL2;
  bool   msgCheck = false;
  uint32_t msgUntil = 0;
  Screen msgReturn = SC_MAIN;
} st;

static String f2(float f) { char b[8]; snprintf(b, sizeof(b), "%.2f", f); return String(b); }

// associa frequencia a um preset (define estacao / RDS)
// devolve o indice do preset com a frequencia atual, ou -1
static int currentPreset() {
  for (int i = 0; i < nPresets; i++)
    if (fabs(presets[i].f - st.freq) < 0.05f) return i;
  return -1;
}

// guarda uma memoria (apend, ate ao maximo)
static bool storePreset(float f, const String& name) {
  if (nPresets >= MAX_PRESET) return false;
  presets[nPresets].f = f;
  String n = name.length() ? name : String("----");
  n.toCharArray(presets[nPresets].name, sizeof(presets[nPresets].name));
  nPresets++;
  return true;
}

// remove uma memoria (desloca as seguintes para tras)
static void removePreset(int idx) {
  if (idx < 0 || idx >= nPresets) return;
  for (int i = idx; i < nPresets - 1; i++) presets[i] = presets[i + 1];
  nPresets--;
  if (st.presetSel >= nPresets) st.presetSel = (nPresets > 0) ? nPresets - 1 : 0;
}

// ---- persistencia das memorias em NVS ("EEPROM" do ESP32) ----
Preferences prefs;
static void savePresetsNVS() {
  prefs.begin("fmradio", false);
  prefs.putInt("n", nPresets);
  prefs.putBytes("presets", presets, sizeof(Preset) * nPresets);
  prefs.end();
}
static void loadPresetsNVS() {
  prefs.begin("fmradio", true);
  nPresets = prefs.getInt("n", 0);
  if (nPresets < 0) nPresets = 0;
  if (nPresets > MAX_PRESET) nPresets = MAX_PRESET;
  if (nPresets > 0) prefs.getBytes("presets", presets, sizeof(Preset) * nPresets);
  prefs.end();
}

// ---- ultima sintonia/volume (restaurado ao ligar) ----
static void saveSettingsNVS() {
  prefs.begin("fmradio", false);
  prefs.putUShort("freq", (uint16_t)lroundf(st.freq * 100));
  prefs.putUChar("vol", (uint8_t)st.volume);
  prefs.putBool("mute", st.muted);
  prefs.end();
}
static void loadSettingsNVS() {
  prefs.begin("fmradio", true);
  uint16_t f = prefs.getUShort("freq", 0);
  st.volume  = prefs.getUChar("vol", st.volume);
  st.muted   = prefs.getBool("mute", false);
  prefs.end();
  if (f >= 8750 && f <= 10800) st.freq = f / 100.0f;
}

// gravacao atrasada das definicoes (evita escritas a cada clique)
static bool     settingsDirty = false;
static uint32_t settingsDirtyAt = 0;
static void markSettingsDirty() { settingsDirty = true; settingsDirtyAt = millis(); }

// --- callbacks de RDS (SI4703) ---
static void rdsServiceName(const char* name) {
  st.station = name;
  st.station.trim();
  if (st.station.length()) st.hasRDS = true;
}
// A RDSParserLocal so chama este callback quando a mensagem de radiotext esta
// COMPLETA (ver RDSParserLocal.cpp), por isso basta sanitizar e mostrar.
// Sanitizamos caracteres nao-imprimiveis (-> espaco) e ignoramos texto vazio.
static void rdsTextCb(const char* text) {
  String t;
  for (const char* p = text; *p && (p - text) < 64; ++p) {
    t += (*p >= 0x20 && *p < 0x7F) ? *p : ' ';
  }
  t.trim();
  if (!t.length()) return;                          // ignora vazio (reset/erros)
  if (t != st.radiotext) st.radiotext = t;
}
static void rdsProcess(uint16_t b1, uint16_t b2, uint16_t b3, uint16_t b4) {
  rds.processData(b1, b2, b3, b4);
}

#if USE_SI4703
// Leitura direta do RDS no SI4703 (registos 0x0A..0x0F), em vez de radio.checkRDS().
//
// Porque: o checkRDS() da biblioteca so entrega o grupo se TODOS os 4 blocos
// forem corrigiveis. No RadioText os caracteres estao nos blocos C e D e o
// indice no bloco B; o bloco A (codigo PI) NAO e preciso. Bastava um erro
// irrecuperavel no bloco A para descartar o grupo inteiro e perder texto bom,
// fazendo a mensagem nunca completar. Aqui ignoramos erros do bloco A.
//
// Bonus: RSSI/estereo saem do mesmo registo 0x0A, evitando uma leitura extra
// (getRadioInfo) que limpava o flag RDSR e tambem fazia perder grupos.
static const uint8_t SI4703_ADDR = 0x10;
static uint32_t      lastRdsPoll = 0;

static void pollSI4703RDS() {
  uint32_t now = millis();
  if (now - lastRdsPoll < 35) return;          // grupos chegam ~a cada 87ms
  lastRdsPoll = now;

  // le 0x0A..0x0F (status + RDS) numa so transacao (6 registos = 12 bytes)
  if (Wire.requestFrom((int)SI4703_ADDR, 12) != 12) return;
  uint16_t reg[6];
  for (int i = 0; i < 6; i++) {
    uint8_t hi = Wire.read();
    uint8_t lo = Wire.read();
    reg[i] = ((uint16_t)hi << 8) | lo;
  }
  uint16_t statusRssi = reg[0];                // 0x0A
  uint16_t readChan   = reg[1];                // 0x0B

  // RSSI (bits 7:0) e indicador de estereo (bit 8) direto do chip
  st.rssi   = constrain((int)map(statusRssi & 0x00FF, 0, 70, 0, 5), 0, 5);
  st.stereo = (statusRssi & 0x0100) != 0;

  if (!(statusRssi & 0x8000)) return;          // RDSR: sem grupo novo pronto

  // indicadores de erro por bloco (0=ok, 1/2=corrigido, 3=irrecuperavel)
  uint8_t blerA = (statusRssi >> 9) & 3;
  uint8_t blerB = (readChan   >> 14) & 3;
  uint8_t blerC = (readChan   >> 12) & 3;
  uint8_t blerD = (readChan   >> 10) & 3;

  // Para o texto precisamos de B, C e D fiaveis; o bloco A nao importa.
  if (blerB == 3 || blerC == 3 || blerD == 3) return;

  // Se o bloco A vier irrecuperavel, passamos 0xFFFF (nao-zero) para o parser
  // nao o confundir com o sinal de reset (block1 == 0).
  uint16_t blockA = (blerA == 3) ? 0xFFFF : reg[2];
  rds.processData(blockA, reg[3], reg[4], reg[5]);   // RDSA, RDSB, RDSC, RDSD
}
#endif

static void applyVolume() {
#if USE_SI4703
  radio.setVolume(map(st.volume, 0, 30, 0, 15));
  radio.setMute(st.muted);
#endif
}

static void applyFreq() {
#if USE_SI4703
  radio.setFrequency((uint16_t)lroundf(st.freq * 100));   // unidades de 10 kHz
  st.station = "";
  st.radiotext = "";
  st.hasRDS = false;
  rds.init();
#else
  st.hasRDS = false;
  st.station = "";
  int p = currentPreset();
  if (p >= 0) { st.station = presets[p].name; st.hasRDS = true; }
#endif
}

#if USE_BATTERY
// Estima a percentagem a partir da tensao da celula (curva de descarga 1S
// aproximada por troços). A LiPo nao e linear, por isso usa-se uma tabela.
static int battPercentFromMv(int mv) {
  static const int lut[][2] = {
    {4200, 100}, {4100, 90}, {4000, 80}, {3900, 70}, {3850, 60}, {3800, 55},
    {3750, 45},  {3700, 35}, {3650, 25}, {3600, 15}, {3500,  8}, {3400, 3}, {3300, 0}
  };
  const int n = sizeof(lut) / sizeof(lut[0]);
  if (mv >= lut[0][0])     return 100;
  if (mv <= lut[n - 1][0]) return 0;
  for (int i = 1; i < n; i++)
    if (mv >= lut[i][0]) {
      int v0 = lut[i][0], p0 = lut[i][1], v1 = lut[i - 1][0], p1 = lut[i - 1][1];
      return p0 + (mv - v0) * (p1 - p0) / (v1 - v0);
    }
  return 0;
}

// Le o ADC (media de 8 amostras) e atualiza estado. A primeira leitura e
// imediata; depois e' refrescada a cada 5 s (a tensao varia devagar).
static void pollBattery() {
  static uint32_t last = 0;
  if (st.battValid && millis() - last < 5000) return;
  last = millis();
  uint32_t acc = 0;
  for (int i = 0; i < 8; i++) acc += analogReadMilliVolts(PIN_VBAT);
  int vbatMv = (int)((acc / 8) * VBAT_DIV);   // tensao real da celula (mV)
  st.battV     = vbatMv / 1000.0f;
  st.battPct   = battPercentFromMv(vbatMv);
  st.battValid = true;
}
#endif

// =================== HELPERS DE DESENHO ====================
// --- gestao da fonte smooth ativa ---
// Uma fonte smooth carregada SOBREPOE-SE as fontes numeradas (mesmo passando o
// numero da fonte ao drawString/textWidth). Por isso descarregamo-la sempre
// antes de desenhar/medir texto com fontes numeradas.
static const uint8_t* gFont = nullptr;
static void fontNumbered() {
  if (gFont) { cv.unloadFont(); gFont = nullptr; }
}
static void fontSmooth(const uint8_t* f) {
  if (gFont != f) {
    if (gFont) cv.unloadFont();
    cv.loadFont(f);
    gFont = f;
  }
}

static void txt(const char* s, int x, int y, uint16_t c, uint8_t font,
                uint8_t datum = TL_DATUM) {
  fontNumbered();
  cv.setTextDatum(datum);
  cv.setTextColor(c, COL_BG);
  cv.drawString(s, x, y, font);
}

// texto com fonte smooth (anti-aliased). O AA mistura com o fundo COL_BG, que e
// limpo a cada frame (fillSprite), por isso nao deixa rasto.
static void stxt(const char* s, int x, int y, uint16_t c, const uint8_t* f,
                 uint8_t datum = TL_DATUM) {
  fontSmooth(f);
  cv.setTextDatum(datum);
  cv.setTextColor(c, COL_BG);
  cv.drawString(s, x, y);
}

static void drawSignal(int x, int y, int level) {
  for (int i = 0; i < 5; i++) {
    int h = 2 + i * 2;
    cv.fillRect(x + i * 3, y + (8 - h), 2, h, (i < level) ? COL_GREEN : COL_DKGREY);
  }
}

// icone de bateria; xr = aresta direita, desenha para a esquerda. Devolve a
// largura ocupada (corpo + terminal) para encadear outros elementos.
static int drawBattery(int xr, int y, int pct) {
  const int w = 16, h = 8;
  int x = xr - w;
  cv.fillRect(xr, y + 2, 2, h - 4, COL_GREY);     // terminal (polo +)
  cv.drawRoundRect(x, y, w, h, 1, COL_GREY);       // contorno
  int fw = (w - 2) * constrain(pct, 0, 100) / 100;
  uint16_t c = (pct <= 20) ? COL_ORANGE : COL_GREEN;
  if (fw > 0) cv.fillRect(x + 1, y + 1, fw, h - 2, c);
  return w + 2;
}

static void drawFooter(const char* a, const char* b, const char* c, const char* d) {
  fontNumbered();                      // medicoes/textos do rodape sao fonte 1
  const char* lbl[4] = {a, b, c, d};
  const uint16_t BTN = 0x05B6;         // teal: cor do "botao" (chip) das acoes
  cv.setTextFont(1);
  cv.setTextDatum(TL_DATUM);
  int cw = LW / 4;
  for (int i = 0; i < 4; i++) {
    int x0 = i * cw;
    int bx = x0 + 3, bw = cw - 6, by = 62, bh = 12;
    cv.fillSmoothRoundRect(bx, by, bw, bh, 3, BTN, COL_BG);  // chip como o preset

    String s = lbl[i];
    char num[2] = {s[0], 0};
    String rest = s.substring(1);                  // inclui o espaco inicial
    int nw = cv.textWidth(num), rw = cv.textWidth(rest);
    int sx = bx + (bw - (nw + rw)) / 2;
    cv.setTextColor(0xFFE0, BTN);                  // numero a amarelo (bom contraste no teal)
    cv.drawString(num, sx, by + 3);
    cv.setTextColor(COL_WHITE, BTN);               // etiqueta a branco
    cv.drawString(rest.c_str(), sx + nw, by + 3);
  }
}

static void drawFrame() {
  cv.fillSprite(COL_BG);
  cv.drawRoundRect(0, 0, LW, LH, 4, COL_FRAME);
}

static void drawScale(int y, float fMin, float fMax, float fCur, bool ticks) {
  int x0 = 14, x1 = LW - 14;
  cv.drawFastHLine(x0, y, x1 - x0, COL_DKGREY);
  if (ticks)
    for (float f = fMin; f <= fMax + 0.1; f += 2) {
      int x = x0 + (int)((f - fMin) / (fMax - fMin) * (x1 - x0));
      cv.drawFastVLine(x, y - 2, 4, COL_GREY);
    }
  int xp = x0 + (int)((fCur - fMin) / (fMax - fMin) * (x1 - x0));
  cv.fillSmoothCircle(xp, y, 3, COL_CYAN, COL_BG);
}

static void drawBigFreq(const char* num, uint16_t col, int yc) {
  fontSmooth(FF_BIG);
  int fw = cv.textWidth(num);
  fontNumbered();
  int mw = cv.textWidth("MHz", 2);
  int x = (LW - (fw + 6 + mw)) / 2;
  stxt(num, x, yc, col, FF_BIG, ML_DATUM);
  txt("MHz", x + fw + 6, yc + 1, COL_GREY, 2, ML_DATUM);
}

static void scrollText(const char* s, int x, int y, int w, int h, uint16_t col) {
  const uint8_t FNT = 2;               // fonte 2 (16px) - um pouco menor que FreeSans
  fontNumbered();                      // garante fonte numerada (nao a smooth)
  cv.setViewport(x, y, w, h, true);
  cv.setTextColor(col, COL_BG);
  int tw = cv.textWidth(s, FNT);
  int yc = h / 2;
  if (tw <= w) {
    cv.setTextDatum(MC_DATUM);
    cv.drawString(s, w / 2, yc, FNT);
  } else {
    cv.setTextDatum(ML_DATUM);
    int gap = 40, period = tw + gap;
    int off = (millis() / 55) % period;
    cv.drawString(s, -off, yc, FNT);
    cv.drawString(s, -off + period, yc, FNT);
  }
  cv.setTextFont(1);
  cv.resetViewport();
}

static void triLeft(int x, int y, int s, uint16_t c)  { cv.fillTriangle(x, y, x + s, y - s, x + s, y + s, c); }
static void triRight(int x, int y, int s, uint16_t c) { cv.fillTriangle(x, y, x - s, y - s, x - s, y + s, c); }

// ================= ICONES (anti-aliased) ===================
// estilo Lucide/Feather: traco ~2px, cantos arredondados, aneis anti-aliased
static void icRadio(int cx, int cy, uint16_t c) {
  // antena diagonal com ponta
  cv.drawWedgeLine(cx + 1, cy - 5, cx + 8, cy - 12, 1.4, 1.4, c, COL_BG);
  cv.fillSmoothCircle(cx + 8, cy - 12, 1, c, COL_BG);
  // corpo (caixa arredondada)
  cv.drawSmoothRoundRect(cx - 11, cy - 5, 3, 2, 22, 13, c, COL_BG);
  // botao/dial
  cv.fillSmoothCircle(cx + 5, cy + 2, 3, c, COL_BG);
  cv.fillSmoothCircle(cx + 5, cy + 2, 1, COL_BG, c);
  // grelha (2 barras arredondadas)
  cv.fillSmoothRoundRect(cx - 8, cy - 1, 8, 2, 1, c, COL_BG);
  cv.fillSmoothRoundRect(cx - 8, cy + 3, 6, 2, 1, c, COL_BG);
}
static void icStar(int cx, int cy, uint16_t c) {
  // marcador (bookmark) preenchido com entalhe em V em baixo
  int w = 13, h = 19, x = cx - w / 2, y = cy - h / 2;
  cv.fillSmoothRoundRect(x, y, w, h, 2, c, COL_BG);
  cv.fillTriangle(x - 1, y + h, x + w + 1, y + h, cx, y + h - 7, COL_BG);
}
static void icSpeaker(int cx, int cy, uint16_t c) {
  cv.fillRect(cx - 9, cy - 3, 5, 6, c);
  cv.fillTriangle(cx - 4, cy, cx + 2, cy - 7, cx + 2, cy + 7, c);
  cv.drawSmoothArc(cx + 2, cy, 8, 7, 235, 305, c, COL_BG, true);
  cv.drawSmoothArc(cx + 2, cy, 12, 11, 235, 305, c, COL_BG, true);
}
static void icSearch(int cx, int cy, uint16_t c) {
  cv.drawSmoothCircle(cx - 2, cy - 2, 7, c, COL_BG);
  cv.drawSmoothCircle(cx - 2, cy - 2, 6, c, COL_BG);
  cv.drawWideLine(cx + 3, cy + 3, cx + 9, cy + 9, 2.5, c, COL_BG);
}
static void icInfo(int cx, int cy, uint16_t c) {
  cv.drawSmoothCircle(cx, cy, 10, c, COL_BG);
  cv.fillSmoothCircle(cx, cy - 4, 1.6, c, COL_BG);
  cv.fillRect(cx - 1, cy - 1, 2, 7, c);
}
// pequeno icone "broadcast": ponto central + ondas dos dois lados
static void icBroadcast(int cx, int cy, uint16_t c) {
  cv.fillSmoothCircle(cx, cy, 2, c, COL_BG);
  cv.drawSmoothArc(cx, cy, 5, 4, 235, 305, c, COL_BG, true);   // onda direita
  cv.drawSmoothArc(cx, cy, 5, 4,  55, 125, c, COL_BG, true);   // onda esquerda
}

// ===================== ECRAS ===============================
static void screenSplash(int f) {
  drawFrame();
  int ax = 38, ay = 30;
  cv.drawWideLine(ax, ay + 20, ax, ay - 4, 2, COL_GREY, COL_BG);
  cv.fillTriangle(ax - 7, ay + 22, ax + 7, ay + 22, ax, ay + 12, COL_GREY);
  cv.fillSmoothCircle(ax, ay - 6, 3, COL_ORANGE, COL_BG);
  for (int i = 0; i < 3; i++) {
    int r = 7 + ((f * 2 + i * 9) % 27);
    cv.drawSmoothArc(ax, ay - 6, r, r - 1, 235, 305, (r < 20) ? COL_CYAN : COL_FRAME, COL_BG, true);
  }
  stxt("FM RADIO", 178, 22, COL_CYAN, FF_BIG, MC_DATUM);
  cv.fillRect(120, 38, 116, 2, COL_ORANGE);
  txt("Sintonizador Estereo", 178, 43, COL_GREY, 1, TC_DATUM);
  int bx = 74, by = 67, bw = 4, gap = 2;
  for (int i = 0; i < 30; i++) {
    int h = 2 + (int)(9 * (0.5 + 0.5 * sin(f * 0.35 + i * 0.55)));
    cv.fillRect(bx + i * (bw + gap), by - h, bw, h, (h > 8) ? COL_ORANGE : COL_GREEN);
  }
}

// Design "cartao de estacao"
static void screenMain() {
  drawFrame();

  // ---- barra de estado (topo) ----
  icBroadcast(11, 7, st.stereo ? COL_GREEN : COL_GREY);
  txt(st.stereo ? "STEREO" : "MONO", 20, 4, st.stereo ? COL_GREEN : COL_GREY, 1);

  // volume ao centro do topo (comum aos dois modos)
  String vol = st.muted ? String("MUTE") : ("VOL " + String(st.volume));
  txt(vol.c_str(), LW / 2, 4, st.muted ? COL_ORANGE : COL_CYAN, 1, TC_DATUM);

  int rx = LW - 10;
#if USE_BATTERY
  if (st.battValid) {                      // bateria no canto direito
    rx -= drawBattery(rx, 2, st.battPct);
    rx -= 4;
  }
#endif
  int pIdx = currentPreset();
  if (pIdx >= 0) {                         // chip da memoria (canto direito)
    char pn[5]; snprintf(pn, sizeof(pn), "P%02d", pIdx + 1);
    int w = 24, h = 11, x = rx - w, y = 1;
    cv.fillSmoothRoundRect(x, y, w, h, 3, COL_ORANGE, COL_BG);
    cv.setTextFont(1);
    cv.setTextDatum(TC_DATUM);
    cv.setTextColor(COL_BG, COL_ORANGE);   // texto preto com fundo laranja (chip)
    cv.drawString(pn, x + w / 2, y + 2);
    rx = x - 6;
  }
  drawSignal(rx - 15, 4, st.rssi);

  if (st.hasRDS) {
    // ---- cartao: barra de acento + nome + frequencia ----
    cv.fillSmoothRoundRect(8, 16, 3, 26, 1, COL_CYAN, COL_BG);
    stxt(st.station.c_str(), 16, 29, COL_WHITE, FF_BIG, ML_DATUM);
    txt((f2(st.freq) + " MHz").c_str(), LW - 12, 29, COL_CYAN, 2, MR_DATUM);
    // separador + ticker do radiotext (altura >= 16 para nao cortar a fonte)
    cv.drawFastHLine(8, 44, LW - 16, COL_FRAME);
    scrollText(st.radiotext.c_str(), 12, 45, LW - 24, 16, 0xC618);  // prata claro (mais visivel que grey)
  } else {
    // ---- sem RDS: frequencia grande + dial da banda ----
    drawBigFreq(f2(st.freq).c_str(), COL_WHITE, 30);
    drawScale(52, FM_MIN, FM_MAX, st.freq, true);
  }

  drawFooter("1 -", "2 +", "3 VOL", "4 PRESET");
}
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
void loop() {
  static uint32_t lastActivity = 0;

  int ev = pollSerial();
  if (!ev) ev = pollButtons();
  if (ev) {
    // log para ajudar a validar os 4 botoes no hardware (passo dos proximos passos)
    if (ev >= 1 && ev <= 4)        Serial.printf("BTN %d: clique curto\n", ev);
    else if (ev >= 11 && ev <= 14) Serial.printf("BTN %d: clique longo\n", ev - 10);
    handleEvent(ev); lastActivity = millis();
  }

  updateScan();

#if USE_BATTERY
  pollBattery();
#endif

#if USE_SI4703
  // RDS + RSSI/estereo lidos diretamente do chip (ver pollSI4703RDS).
  if (!st.scanning) pollSI4703RDS();
#endif

  if (st.screen == SC_MSG && millis() > st.msgUntil) st.screen = st.msgReturn;

  // grava definicoes 2s depois da ultima alteracao (sintonia/volume)
  if (settingsDirty && millis() - settingsDirtyAt > 2000) {
    settingsDirty = false;
    saveSettingsNVS();
  }

  // inatividade: ao fim de 30s volta ao principal (excepto durante o scan)
  if (st.screen != SC_MAIN && st.screen != SC_MSG && !st.scanning &&
      millis() - lastActivity > 30000) {
    st.screen = SC_MAIN;
  }

  render();
  show();
  delay(15);
}

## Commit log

2026-06-16 Add initial firmware for ESP32-S2 Mini FM Radio with ST7789 display
    - Created platformio.ini for project configuration
    - Implemented main application logic in main.cpp
    - Integrated TFT_eSPI library for display handling
    - Added support for SI4703 FM radio module with RDS functionality
    - Implemented user interface for tuning, volume control, and presets
    - Included EEPROM-like storage for presets and settings using Preferences library
    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
2026-06-16 Enhance RDS text handling to ignore empty messages and prevent incomplete repetitions
    [main.cpp]
2026-06-20 Add 3D case design and battery monitoring features for FM Radio project
    - Introduced a new OpenSCAD file for the 3D case design of the FM Radio using ESP32-S2 Mini and SI4703, featuring improved aesthetics and printability.
    - Added preview images for the faceplate and isometric views of the case.
    - Updated main.cpp to include battery monitoring functionality, allowing for LiPo battery voltage reading and percentage estimation.
    - Modified button handling to support a membrane keypad and added functionality to remove presets from memory.
    - Enhanced user interface to display battery status on the main screen.
    [body.stl, faceplate.stl, fmradio_case.scad]
2026-06-20 Add 3D case design details for printing in README
2026-06-20 Update README and code comments to clarify keypad wiring and avoid potential short circuits
    [main.cpp]
2026-06-20 Update README to enhance wiring diagram clarity and power supply details
2026-06-27 Refactor LCD dimensions and add retention frame
    - Adjusted edge margins and gap sizes for speaker and LCD components.
    - Updated LCD dimensions to reflect actual measurements and added comments for clarity.
    - Introduced functions for LCD retention frame and flat-flex connector cutout.
    - Modified faceplate module to incorporate new LCD window dimensions and retention features.
    - Changed TFT display rotation in main setup for correct orientation.
    - Added new STL file for FM Radio plate.
    [FMRadio_plate.stl, body.stl, faceplate.stl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]
2026-06-27 Update 3D model files and adjust cable slot dimensions for improved fit
    [FMRadio_plate.stl, body.stl, faceplate.stl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]
